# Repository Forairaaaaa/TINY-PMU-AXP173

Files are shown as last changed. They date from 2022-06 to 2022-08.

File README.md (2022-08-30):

# 【TINY-PMU】AXP173
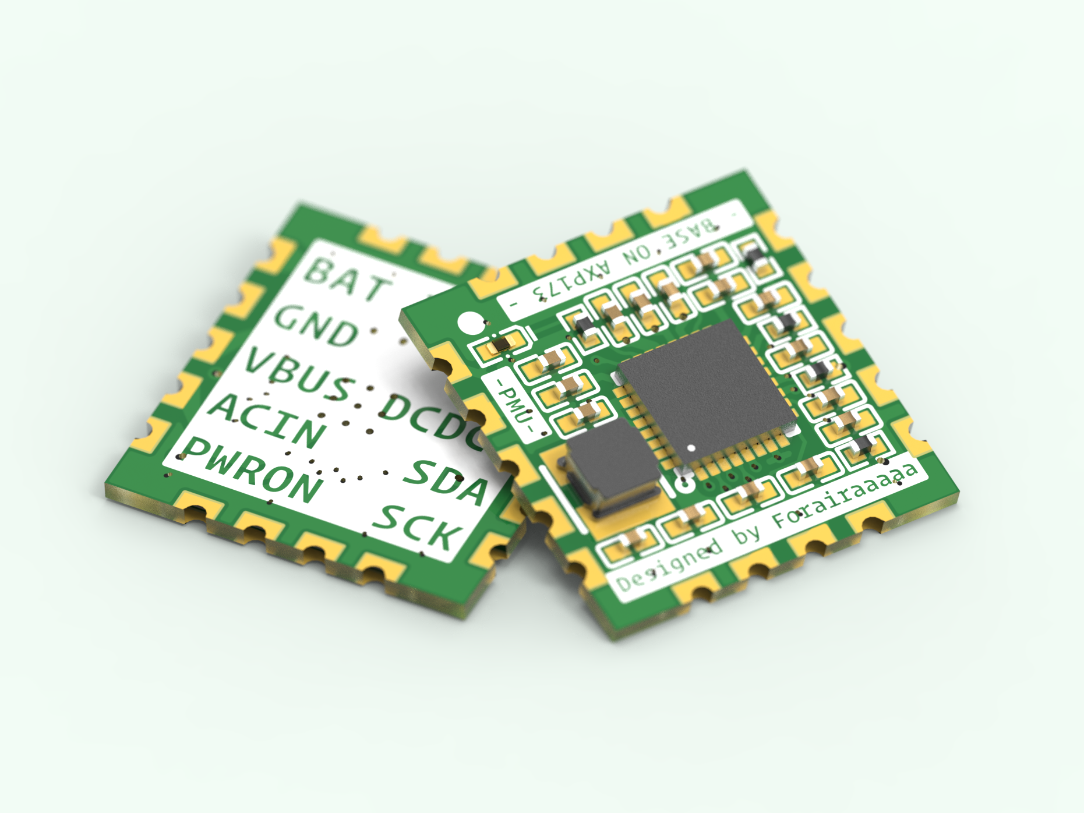
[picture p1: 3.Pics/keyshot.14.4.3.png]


#### 超迷你的电源管理模块，适用于带电池的小型移动设备和机器人等~

视频介绍：

立创工程：

- 超迷你： **1.6cm x 1.52cm**，基于**AXP173**，集成核心电路，连接即用
- 引脚由2.54mm间距半孔引出，可焊接排针直接连接杜邦线使用，方便测试开发~
- 常规工艺加工亦可

#### 功能简述：

- 可控DCDC、LDO电源输出
- 电池温度、电量、充放电信息等

#### 适配Arduino库：

- [Forairaaaaa/TinyPMU: Arduino libaray for TINY-PMU](https://github.com/Forairaaaaa/TinyPMU)

#### 注意事项：

- 一定要注意AXP173的货源，有默认电压低而无法启动MCU的风险
- 为减少体积，未引出DCDC-2相关引脚
- 布线宽度受限，不建议负载电流过大

#### 参考链接：

- [www.x-powers.com](http://www.x-powers.com/index.php/Info/product_detail/article_id/27)

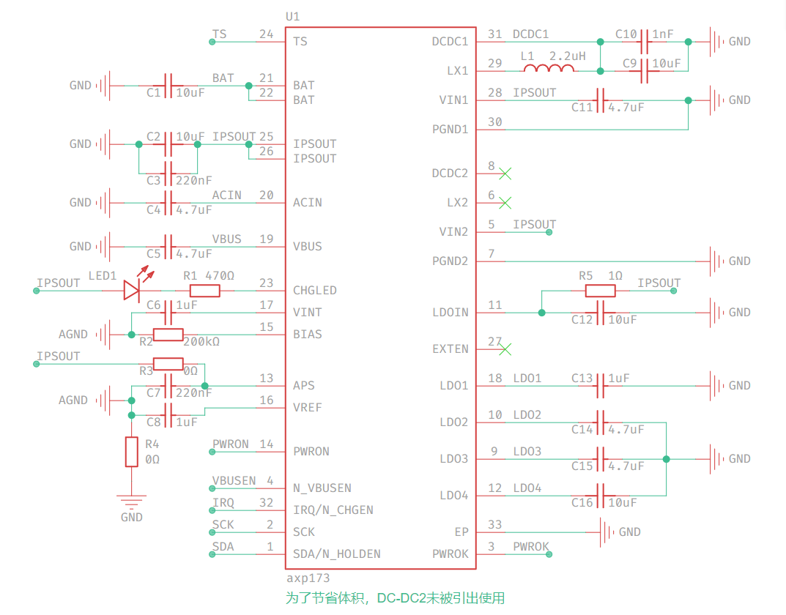
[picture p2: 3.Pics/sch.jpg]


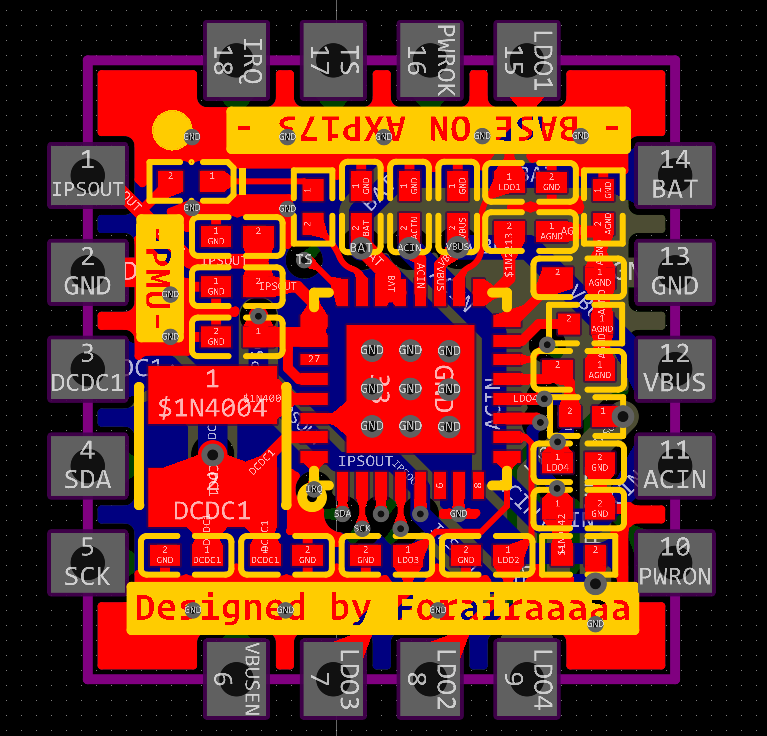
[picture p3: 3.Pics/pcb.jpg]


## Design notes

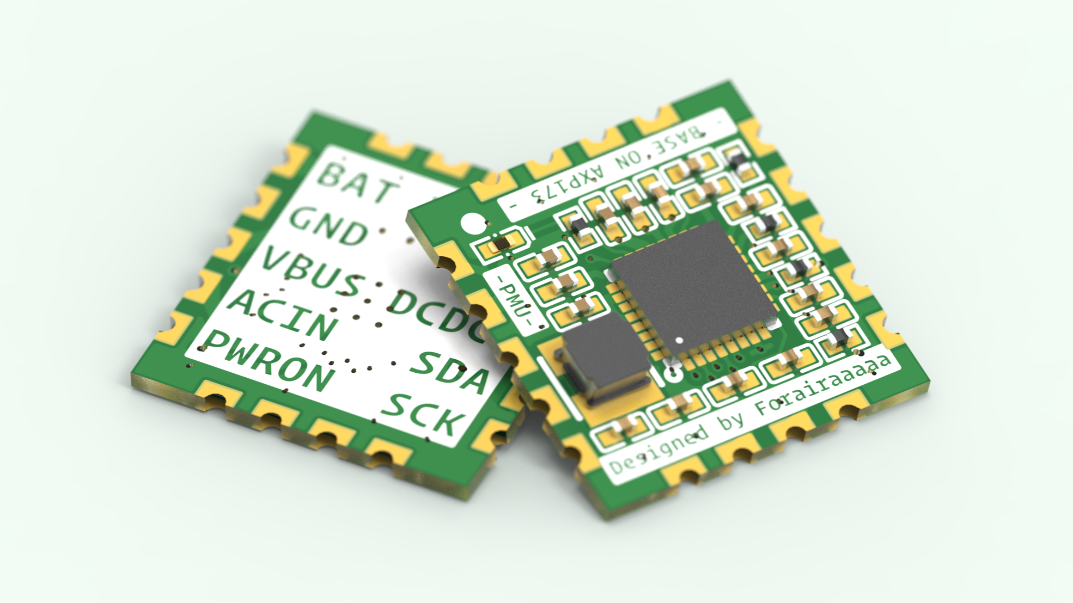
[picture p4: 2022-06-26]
3.Pics/keyshot.14.16.9.png

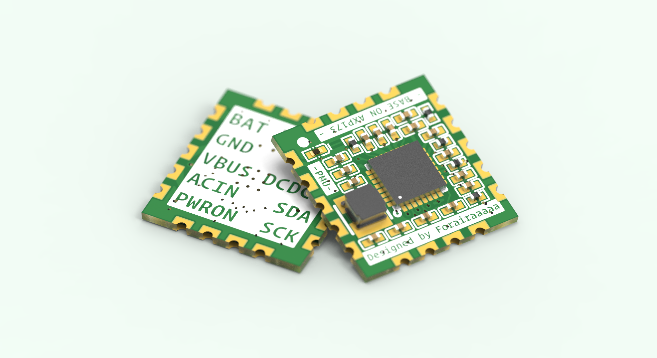
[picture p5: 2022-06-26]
3.Pics/keyshot.14.png

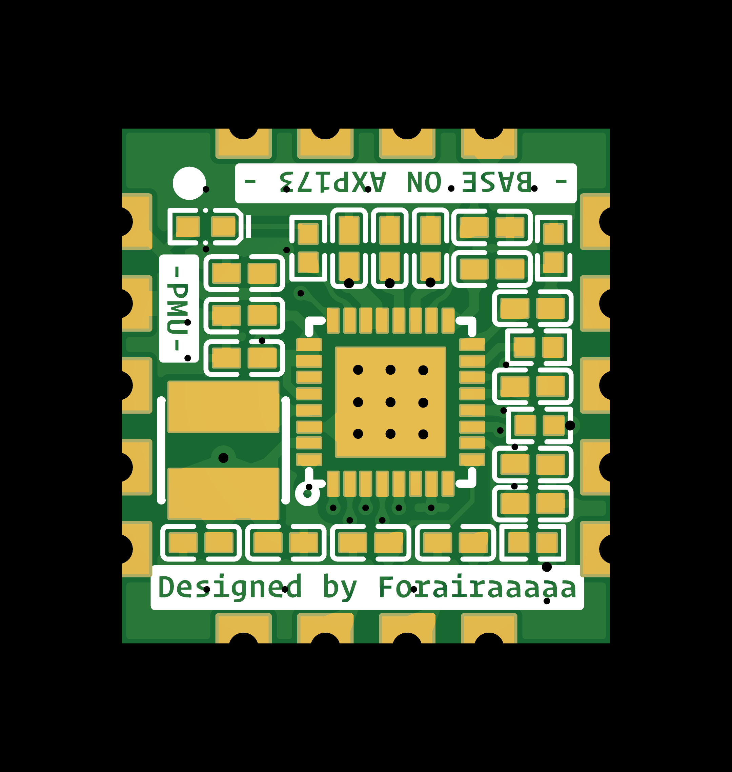
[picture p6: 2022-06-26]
3.Pics/f.png

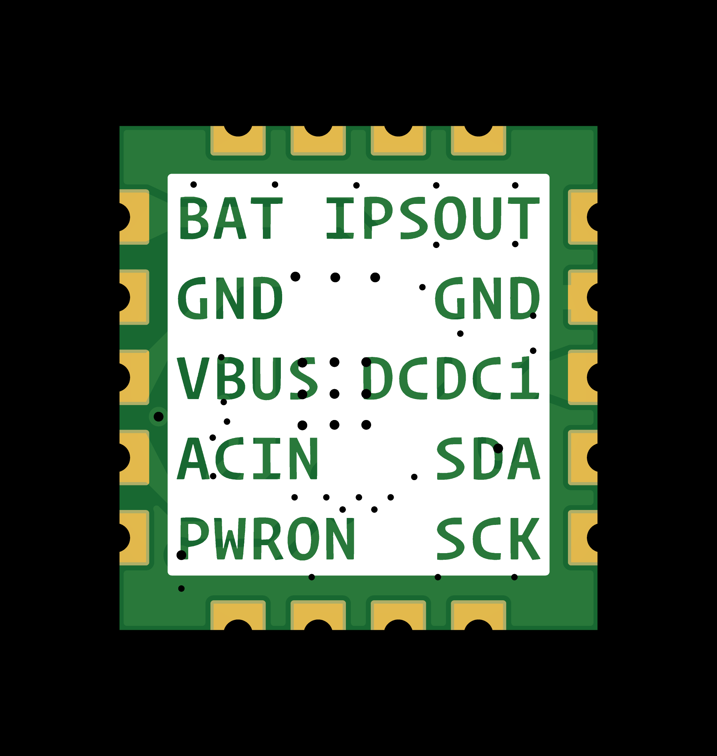
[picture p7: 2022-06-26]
3.Pics/b.png

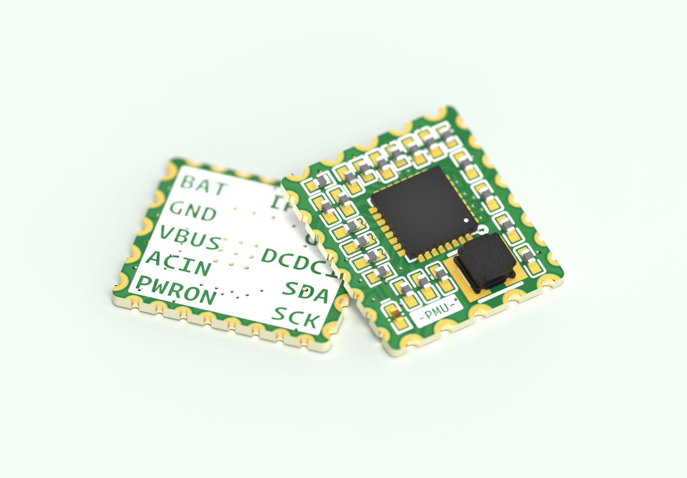
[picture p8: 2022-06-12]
3.Pics/KeyShot渲染.9.png

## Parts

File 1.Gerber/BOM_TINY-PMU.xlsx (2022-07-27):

No. | Quantity | Device | Designator | Footprint | Value | Manufacturer Part | Manufacturer | Supplier Part | Supplier
1 | 5 | cl05a106mp5nunc | C1,C2,C9,C12,C16 | C0402 | 10uF | CL05A106MP5NUNC | SAMSUNG(三星) | C315248 | LCSC
2 | 1 | cl05b224ko5nnnc | C3 | C0402 | 220nF | CL05B224KO5NNNC | SAMSUNG(三星) | C16772 | LCSC
3 | 4 | cl05a475mp5nrnc | C4,C5,C14,C15 | C0402 | 4.7uF | CL05A475MP5NRNC | SAMSUNG(三星) | C23733 | LCSC
4 | 2 | cl05a105kp5nnnc | C6,C8 | C0402 | 1uF | CL05A105KP5NNNC | SAMSUNG(三星) | C14445 | LCSC
5 | 1 | cl05b224ko5nnnc | C7 | c0402 | 220nF | CL05B224KO5NNNC | SAMSUNG(三星) | C16772 | LCSC
6 | 1 | cc0402krx7r9bb102 | C10 | C0402 | 1nF | CC0402KRX7R9BB102 | YAGEO(国巨) | C106205 | LCSC
7 | 1 | cl05a475mp5nrnc | C11 | c0402 | 4.7uF | CL05A475MP5NRNC | SAMSUNG(三星) | C23733 | LCSC
8 | 1 | cl05a105kp5nnnc | C13 | c0402 | 1uF | CL05A105KP5NNNC | SAMSUNG(三星) | C14445 | LCSC
9 | 1 | swpa3015s2r2mt | L1 | IND-SMD_L3.0-W3.0 | 2.2uH | SWPA3015S2R2MT | Sunlord(顺络) | C43389 | LCSC
10 | 1 | ncd0402y1 | LED1 | LED0402-RD |  | NCD0402Y1 | 国星光电 | C130721 | LCSC
11 | 1 | 0402wgf4700tce | R1 | R0402 | 470Ω | 0402WGF4700TCE | UNI-ROYAL(厚声) | C25117 | LCSC
12 | 1 | 0402wgf2003tce | R2 | R0402 | 200kΩ | 0402WGF2003TCE | UNI-ROYAL(厚声) | C25764 | LCSC
13 | 1 | 0402wgf0000tce | R3 | r0402 | 0Ω | 0402WGF0000TCE | UNI-ROYAL(厚声) | C17168 | LCSC
14 | 1 | 0402wgf0000tce | R4 | R0402 | 0Ω | 0402WGF0000TCE | UNI-ROYAL(厚声) | C17168 | LCSC
15 | 1 | 0402wgf100ktce | R5 | r0402 | 1Ω | 0402WGF100KTCE | UNI-ROYAL(厚声) | C25086 | LCSC
16 | 1 | axp173 | U1 | qfn-32l_l5.0-w5.0-p0.50-ep

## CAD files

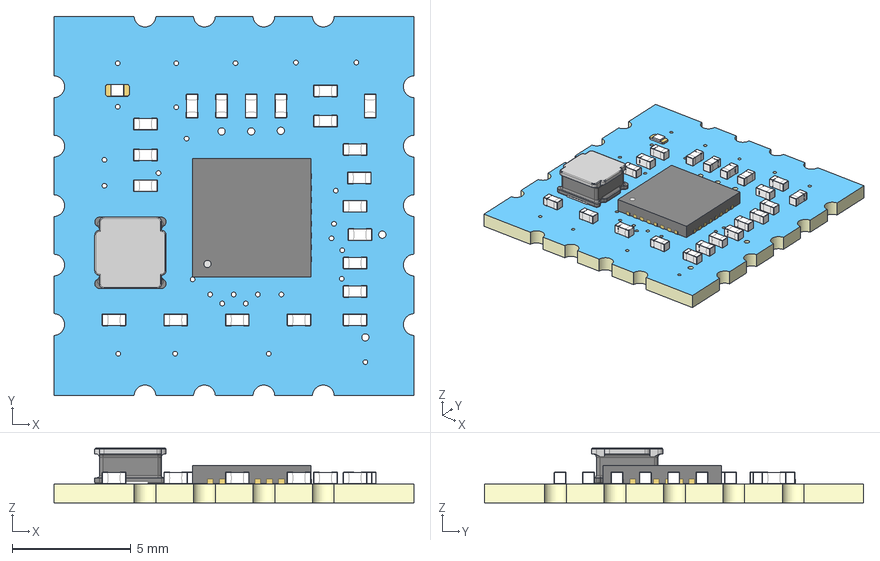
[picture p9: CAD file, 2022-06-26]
2.Models/3D_TINY-PMU-AXP173_V2.step
15.1 x 16.0 x 2.31 mm
=>[0:1:1:5] x 5
=>[0:1:1:16] x 16

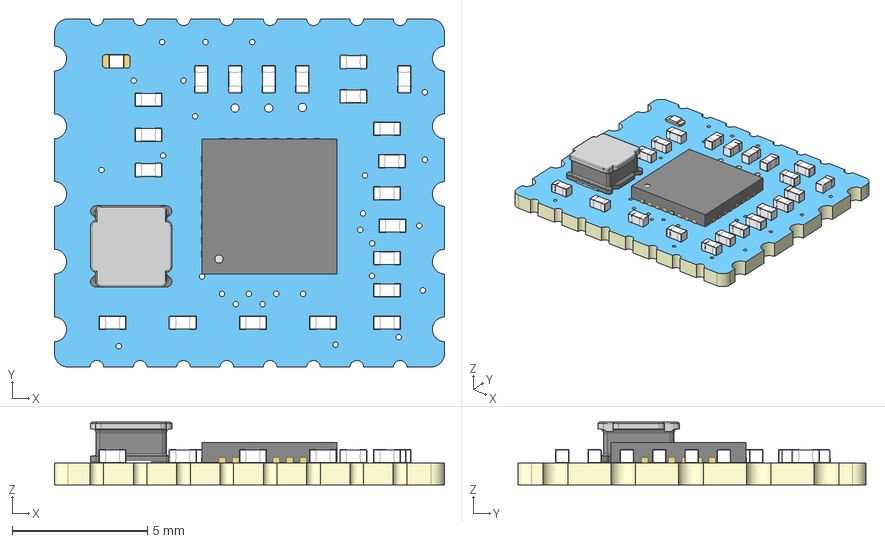
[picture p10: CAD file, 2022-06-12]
2.Models/3D_MINI-PMU-AXP173.step
14.4 x 12.8 x 2.31 mm
=>[0:1:1:5] x 5
=>[0:1:1:22] x 16

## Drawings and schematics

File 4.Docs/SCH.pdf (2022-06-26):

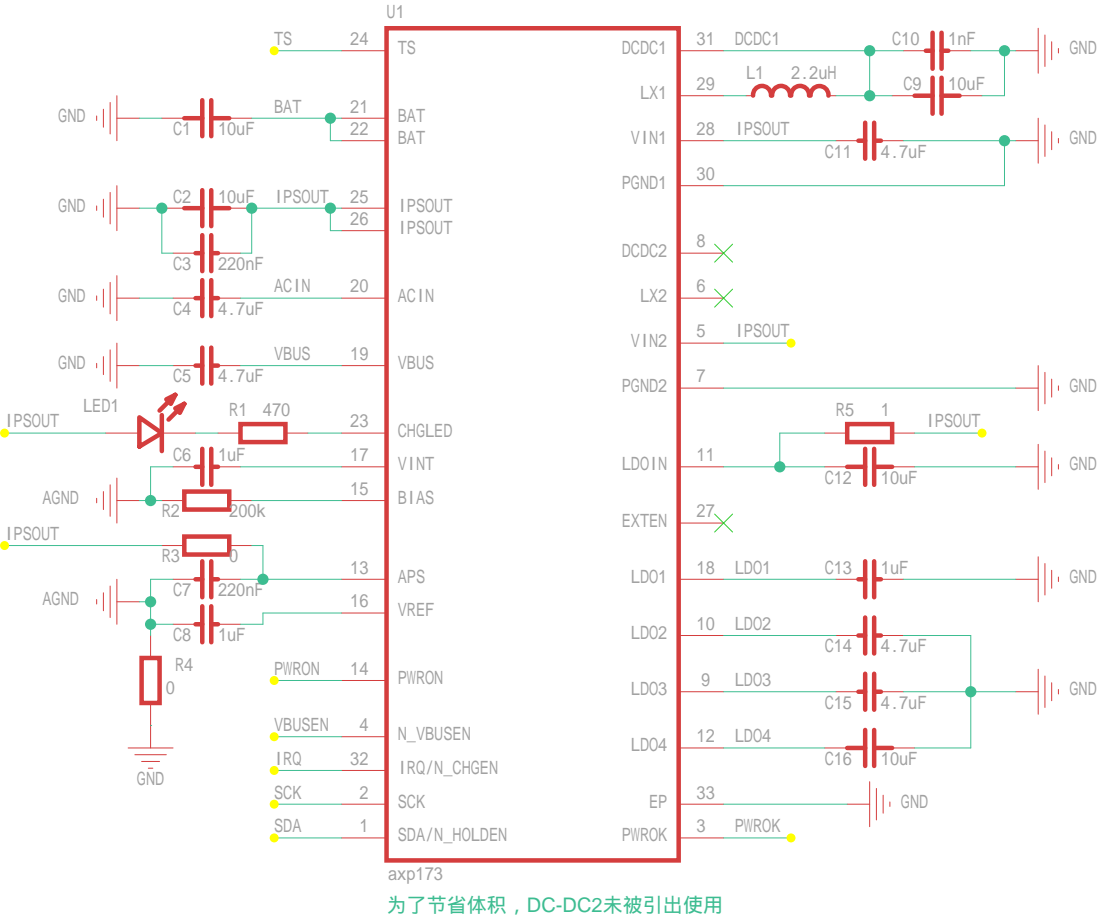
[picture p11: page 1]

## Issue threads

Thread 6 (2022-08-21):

Bom存在重复项目

ShigemoriHakura, 2022-08-21:
C3, C7 footprint大小写不匹配 料号C16772
R3, R4 footprint大小写不匹配 料号C17168
C4,C5,C14,C11,C15 footprint大小写不匹配 料号C23733
C6,C8,C13 footprint大小写不匹配 C14445

Forairaaaaa, 2022-08-21:
用项目文件直接导出试试目文件直接导出试试

Forairaaaaa, 2022-08-21:
应该是之前的项目文件版本对不上，现在换到新版了

Closed 2022-08-28.

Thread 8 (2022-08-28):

买到的AXP173 默认DCDC电压是1.8v

ShigemoriHakura, 2022-08-28:
有没有推荐的店铺出厂是3.3v的？
或者如何设置默认电压（i2c设置的断电重新上就失效了

ShigemoriHakura, 2022-08-28:
（还有个问题 PowerOK怎么都不出

Forairaaaaa, 2022-08-28:
我之前买的铺子货源也不行，纯属是运气好，powerok估计也是默认配置的问题

ShigemoriHakura, 2022-08-28:
hmmm，那只能去官网订购了？

Forairaaaaa, 2022-08-29:
可以进[https://space.bilibili.com/14689020](url)他的群看看，我记得有群友找到正常的铺子

ShigemoriHakura, 2022-08-29:
（在他的视频和动态里面并没有看见有群(´･_･`)

Forairaaaaa, 2022-08-29:
这样吗，你找他私聊看看（心虚

ShigemoriHakura, 2022-08-29:
额。。。其实说来惭愧我并不擅长和人实时交流
实在不行我觉得我去画个tp4056也能满足需求了
（但是建议在项目提醒一下AXP173的问题，感觉这个坑巨大

Forairaaaaa, 2022-08-30:
可以~

ShigemoriHakura, 2022-08-30:
翻了半天翻到 2021-03-29 的视频下面有个群。。。ESP32交流群？

Forairaaaaa, 2022-08-30:
好像是

Forairaaaaa, 2022-11-03:
【[自制开源]AXP173 PMIC电源管理芯片最全资料】 https://www.bilibili.com/video/BV1Le411T74p/?share_source=copy_web&vd_source=b4381b353b0a6b484d18d44cbedc624a

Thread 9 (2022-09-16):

如何测试电源模块是否正常？

LebinLiang, 2022-09-16:
（项目应用在up主的小电视中）目前没有接电池，VBUS上电5V后vcc无输出电压，按了PWR，指示灯也没有反应。想问问需要如何检测电源模块的输出以及设置呢？淘宝买的原装出场，自己手工smt

tannerhu, 2022-09-25:
指示灯USB充电时才会亮，BAT上电3.7V，PWRON接地一下放开，DCDC1就会输出3.3V了

LebinLiang, 2022-09-25:
>

我换了一家店买了新的芯片成功了，谢谢你。想问问你有复刻up主另外一个项目[Chappie-Core](https://github.com/Forairaaaaa/Chappie-Core)吗

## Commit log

2022-06-26 update v2
    [3D_MINI-PMU-AXP173.step, 3D_TINY-PMU-AXP173_V2.step]
2022-07-27 add BOM and PickAndPlace
    [BOM_TINY-PMU.xlsx, PickAndPlace_TINY-PMU.xlsx]
